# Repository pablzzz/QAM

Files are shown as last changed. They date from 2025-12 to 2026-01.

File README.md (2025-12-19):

# The Quadrant Actuator Machine (QAM)
## Introduction
The Quadrant Actuator Machine (QAM) is an arena for experimental tests that consists of a removable Petri dish, four pull-type electromagnets and four quadrant-shaped hammers, separated by a margin and two walls to minimize vibration cross-talk. A PETG 3D-printed base holds the four electromagnets fitted with hammers. Another 3D-printed structure, (the crown holding the Petri dish), sits on top of it, held in place by a pair of 3D-printed grips. See the full documentation [here](The_Quadrant_Actuator_Machine.pdf).

<p align="center">
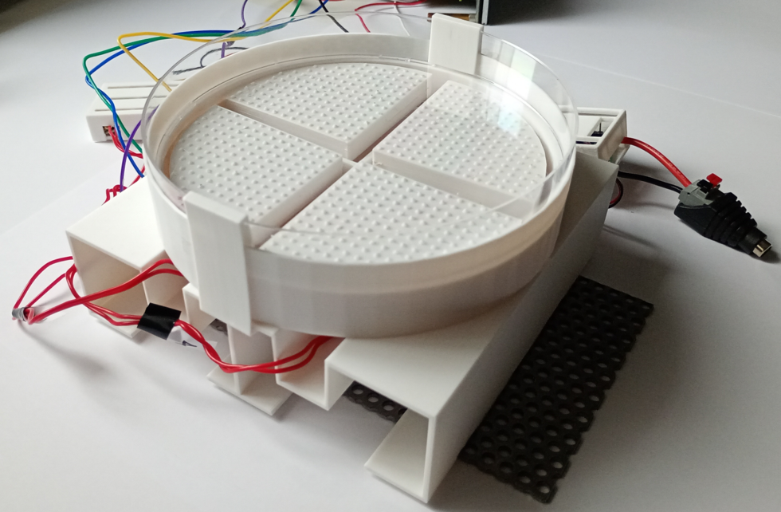
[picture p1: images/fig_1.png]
  
  Picture of the final version of the Slim QAM.
</p>

The creation of the QAM was supported by the strategic programme Excellence Initiative at Jagiellonian University, Poland (RSM/122/FP).

## Programming

The I<sup>2</sup>C PWM board was programmed in Python to drive the solenoids as shown below. The quadrants are
denoted by *Q<sub>i</sub>* where *i* is any of the 4 available quadrants in the Petri dish and *Q<sub>i</sub>* ∈ {OFF, LOW, MEDIUM, HIGH}.

| Value | Description |
|---|---|
| OFF | The electromagnet is not being acted upon. |
| LOW | The electromagnet taps the Petri dish 4 times per second. |
| MEDIUM | The electromagnet taps the Petri dish 8 times per second. |
| HIGH | The electromagnet taps the Petri dish 16 times per second. |

The Python file `quadrant_operation.py` contains all the relevant code. To operate the PCA9685, the
following library has to be installed: `adafruit-circuitpython-pca9685`. For example, to activate only the
fourth quadrant at 4 taps/s, the script can be called like this:
`pi@raspberrypi:~/qam$ quadrant_operation.py LOW [0,0,0,1]`

## Example dataset obtained using the QAM

The QAM was tested by performing experiments on a model organism to gather data to extend the Vicsek
model (a swarm behavior model).

<p align="center">
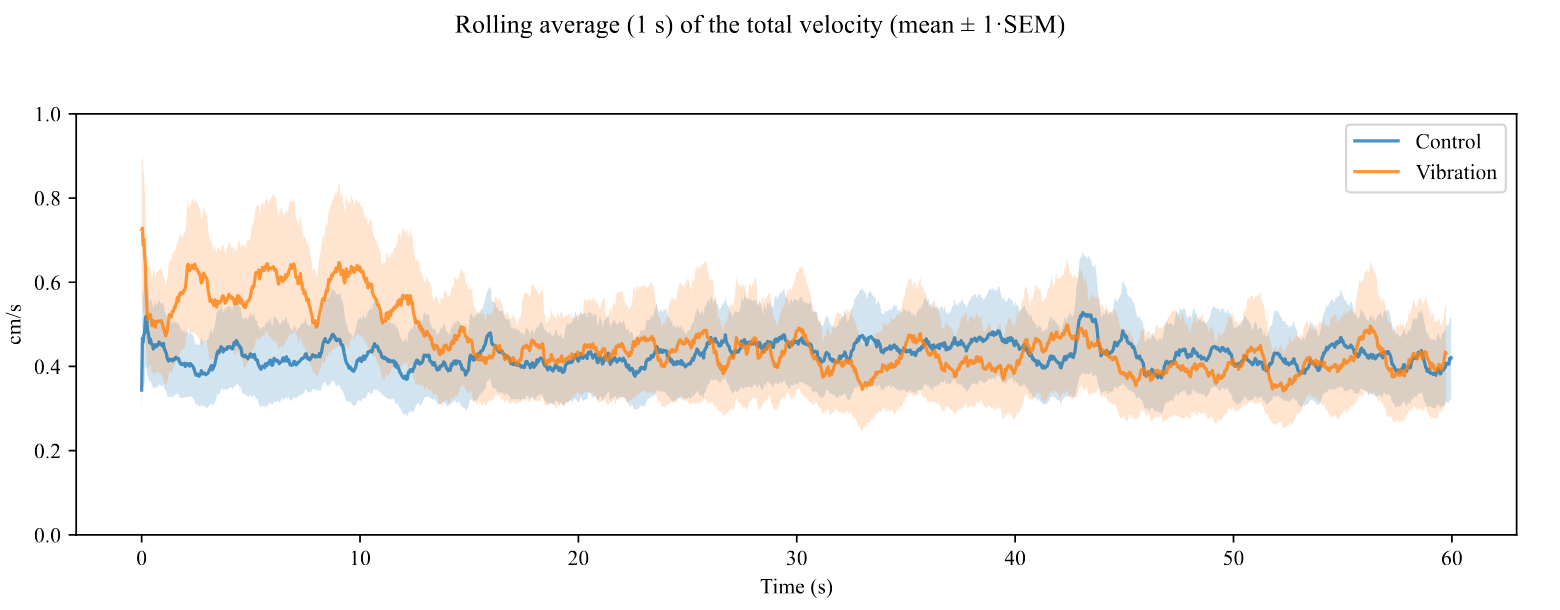
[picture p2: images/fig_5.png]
  
  Control vs Vibration setup on the QAM (speed).
</p>

<p align="center">
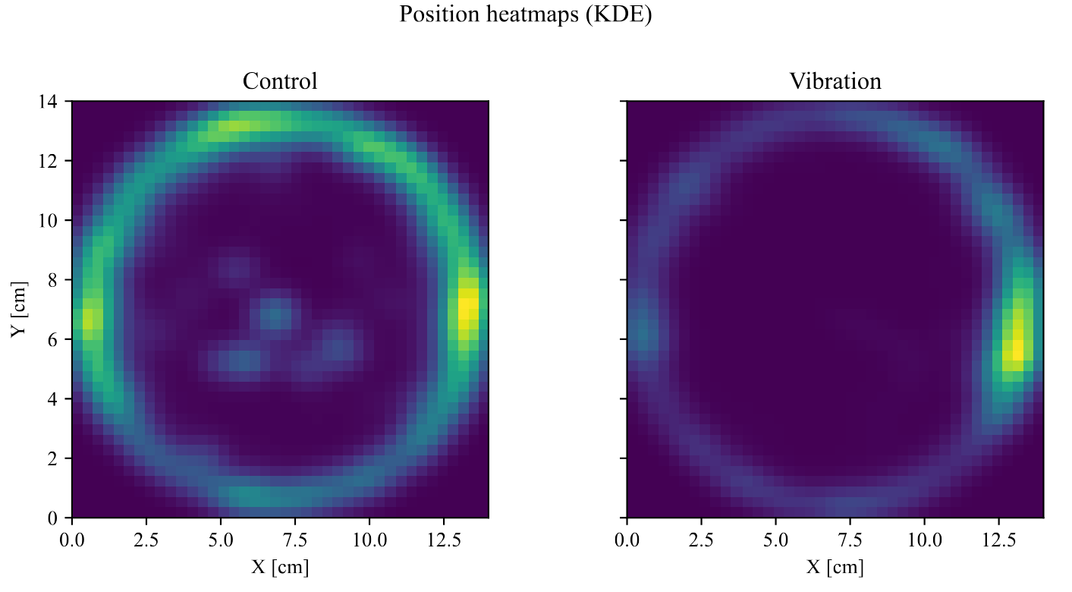
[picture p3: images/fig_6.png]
  
  Control vs Vibration setup on the QAM (KDE heatmaps). Both leftmost quadrants were active
  in the Vibration group. Note the avoidance of the active quadrants.
</p>

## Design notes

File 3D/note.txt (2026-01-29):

Prusa PETG filament was used for all 3D prints.

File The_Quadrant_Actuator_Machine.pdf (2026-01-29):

## The Quadrant Actuator Machine (QAM)

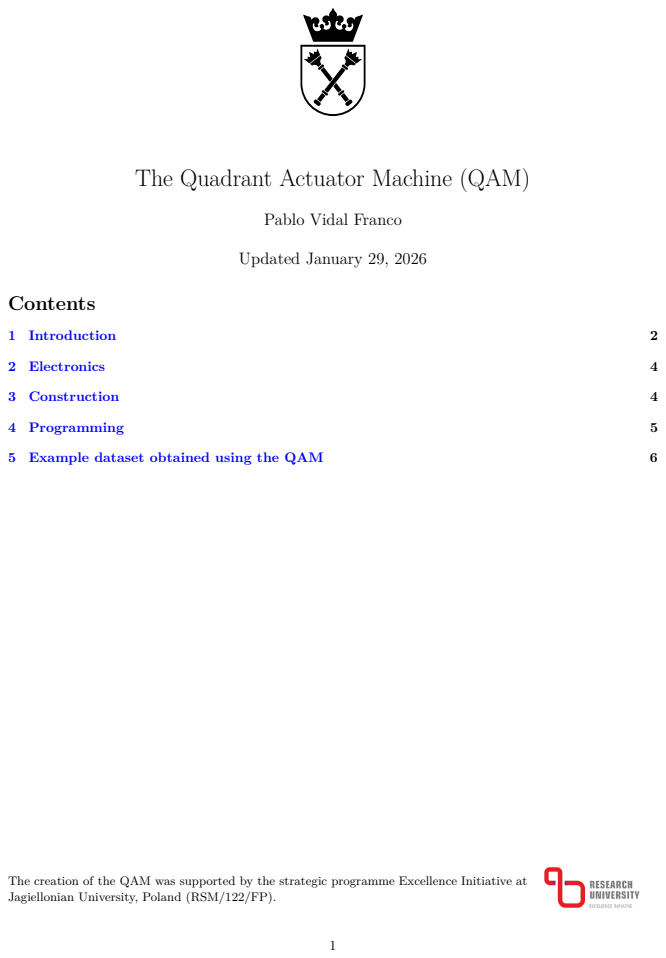
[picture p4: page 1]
Updated January 29, 2026; Contents; 1 Introduction; 2 Electronics; 3 Construction; 4 Programming; 5 Example dataset obtained using the QAM

Pablo Vidal Franco

The creation of the QAM was supported by the strategic programme Excellence Initiative at
Jagiellonian University, Poland (RSM/122/FP).

## 1 Introduction

The Quadrant Actuator Machine (QAM) is an arena for experimental tests that consists of a removable Petri dish, four pull-type electromagnets and four quadrant-shaped hammers, separated by a margin and two walls to minimize vibration cross-talk. A PETG 3D-printed base holds the four electromagnets fitted with hammers. Another 3D-printed structure, (the crown holding the Petri dish), sits on top of it, held in place by a pair of 3D-printed grips (Figure 1). A prototype of the QAM was also built but it was discarded as its weight would not make it practical for transport (Figure 2). Table 1 shows the materials used during the construction of the prototype and the final version. I designed and assembled both the final QAM and the prototype. I also tested the machine on terrestrial isopods.


Figure 1: Picture of the final version of the Slim QAM.

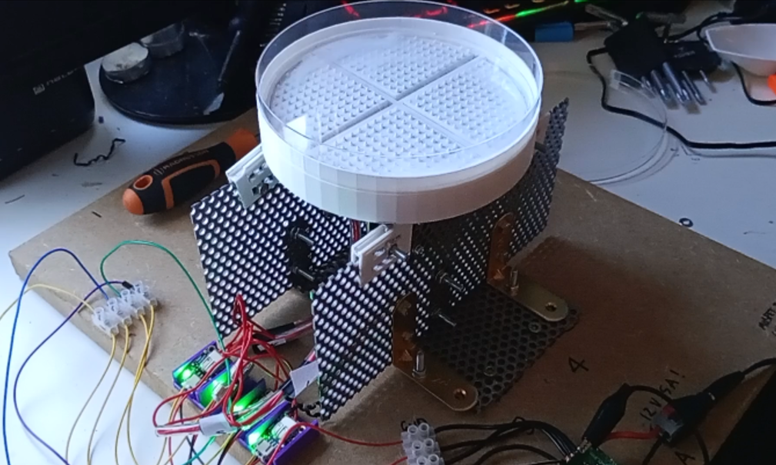
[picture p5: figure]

Figure 2: Picture of the QAM prototype.

Table 1: Materials used for the construction of the QAM prototype and the Slim QAM.

Item | Purpose | Number
140 mm diameter PET Petri dish | Removable part of machine forming the arena. | 1
40 x 30 x 2 cm wooden sheet | Main support for the steel sheets and machine. | 1
Perforated 20 x 10 x 0.2 cm steel sheet | Support for the electromagnets. | 3
M3 screw | Attach the steel sheet to the wooden sheet. | 4
L-brackets | Attach the steel sheets other steel sheets. | 6
M3 bolt, nut and washer | Attach L-brackets to the steel sheets. | 32
M1 bolt, nut and washer | Attach the 3D-printed pieces to the steel sheets. | 4
Super glue | Bolt fixing in the prototype. | 1
8 mm screw terminals 10A/250V | Wiring prototypes and final connections. | 12
PVC wire set / wire | | 1
Power supply 12V/5A | Power supply for the electromagnets. | 1
DC 5.5×2.1 mm power jack | Split the power into a PCB adapter. | 1
Adapter PCB | Distribute (+) and (-) to electromagnets. | 1
Raspberry Pi 5 | Control the electromagnets and record data. | 1
I²C PWM driver | Interface to control the electromagnets. | 1
N-channel MOSFET driver | | 4
12V 12W pull-type electromagnet | Produce vibrations on-demand (prototype). | 4
12V 8W pull-type electromagnet | Produce vibrations on-demand (final version). | 4
Solder roll | Solder connections. | 1
PETG filament roll | 3D-print prototypes and final versions of the ham-
| mers sitting on the electromagnets, and the Petri
| dish supports. | 2

## 2 Electronics

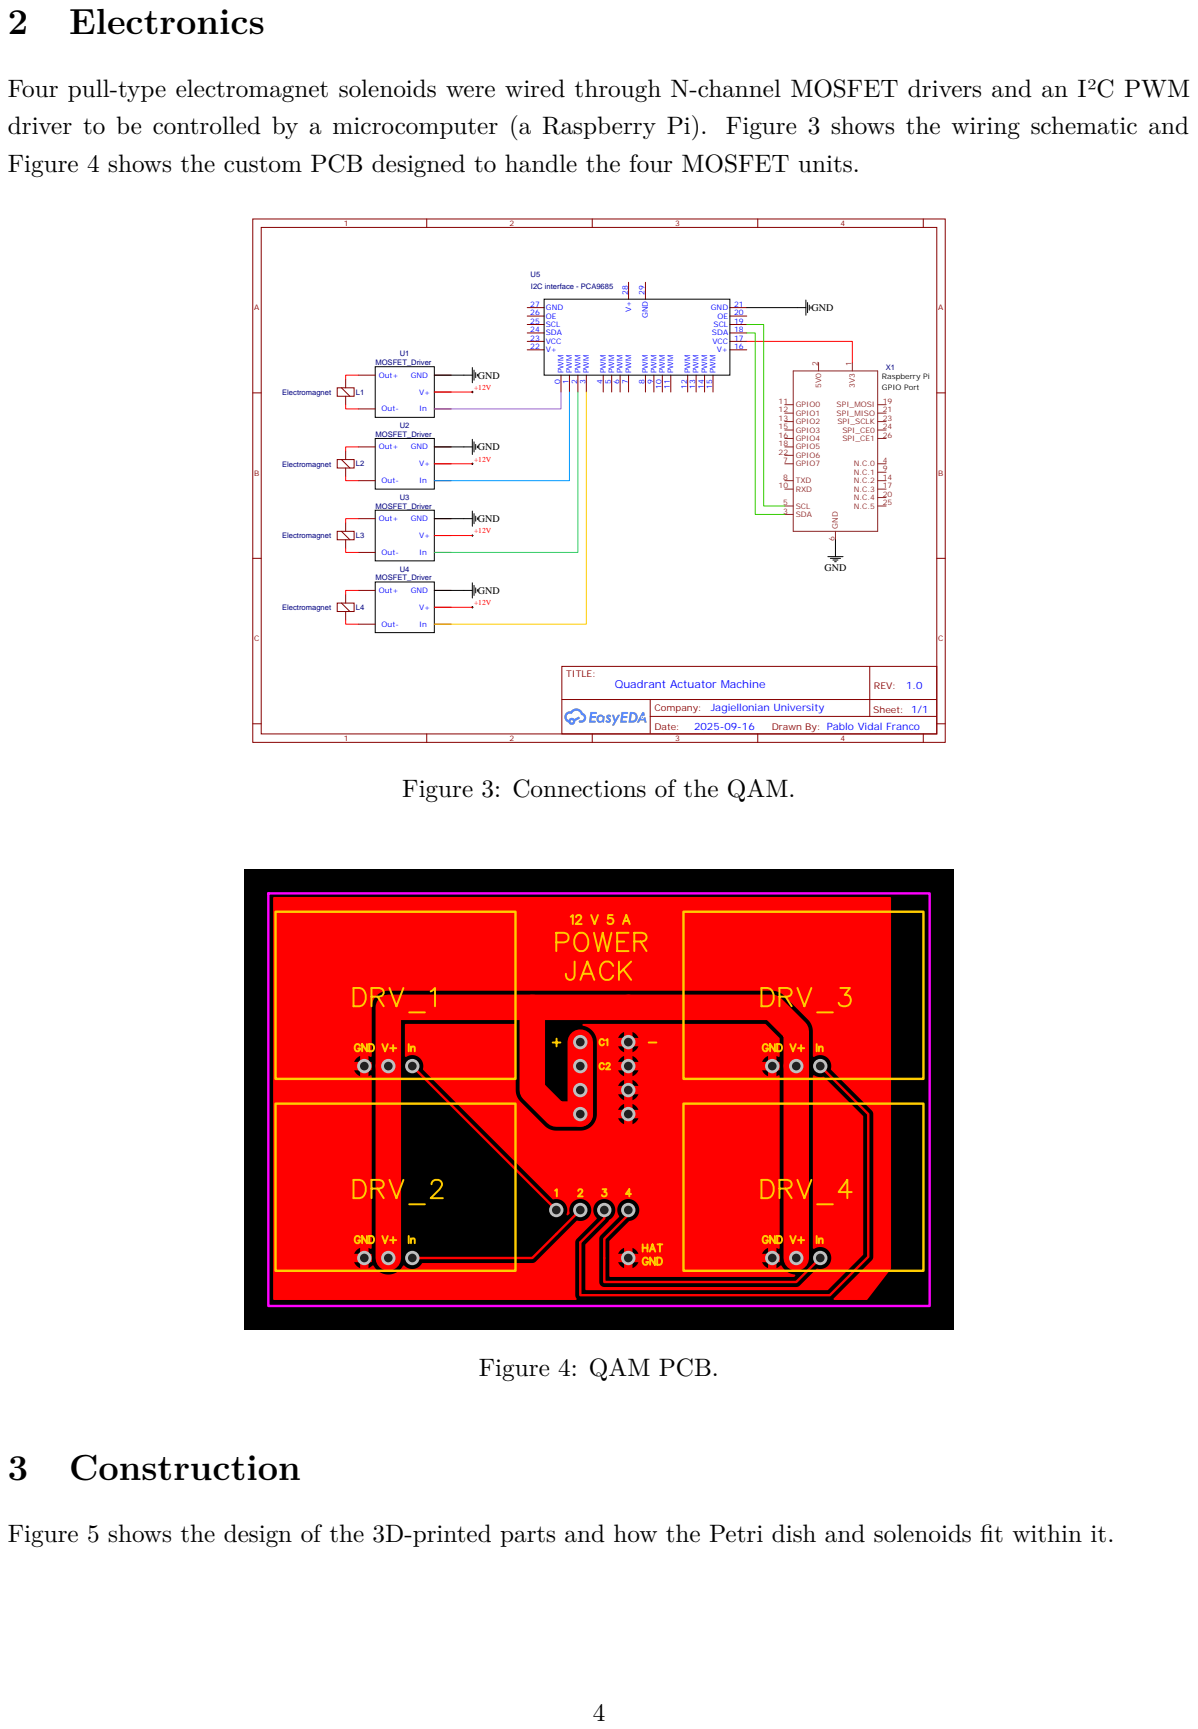
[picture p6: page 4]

Four pull-type electromagnet solenoids were wired through N-channel MOSFET drivers and an I²C PWM
driver to be controlled by a microcomputer (a Raspberry Pi). Figure 3 shows the wiring schematic and
Figure 4 shows the custom PCB designed to handle the four MOSFET units.

V+ 22 VCC 23 SDA 24 SCL 25 OE 26 GND 27

V+ 16 VCC 17 SDA 18 SCL 19 OE 20 GND 21

Drawn By: Pablo Vidal Franco

Figure 3: Connections of the QAM.

Figure 5 shows the design of the 3D-printed parts and how the Petri dish and solenoids fit within it.

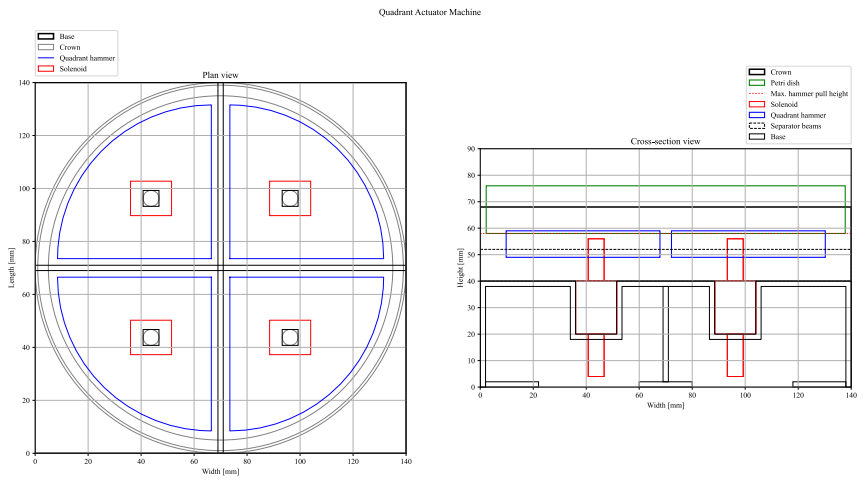
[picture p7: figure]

Figure 5: Plan view and side view of the Slim QAM.

## 4 Programming

The I²C PWM was programmed in Python to drive the solenoids as shown in Table 2. The quadrants are denoted by Qi where i is any of the 4 available quadrants in the Petri dish and Qi ∈ {OFF, LOW, MEDIUM, HIGH}.

Table 2: Values of Qi and descriptions.

Value | Description
OFF | The electromagnet is not being acted upon.
LOW | The electromagnet taps the Petri dish 4 times per second.
MEDIUM | The electromagnet taps the Petri dish 8 times per second.
HIGH | The electromagnet taps the Petri dish 16 times per second.

The Python file quadrant_operation.py contains all the relevant code. To operate the PCA9685, the following library has to be installed: adafruit-circuitpython-pca9685. For example, to activate only the fourth quadrant at 4 taps/s, the script can be called like this:

pi@raspberrypi:~/qam$ quadrant_operation.py LOW [0,0,0,1]

## 5 Example dataset obtained using the QAM

The QAM was tested by performing experiments on a model organism to gather data to extend the Vicsek

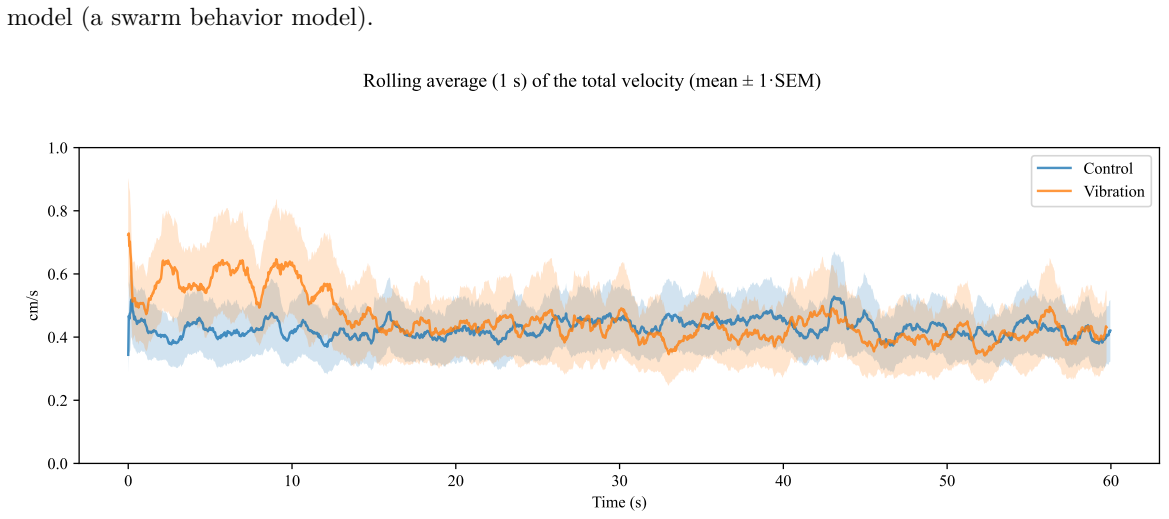
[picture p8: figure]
model (a swarm behavior model).; Time (s); Control Vibration

Rolling average (1 s) of the total velocity (mean ± 1·SEM)

Figure 6: Control vs Vibration setup on the QAM (speed).

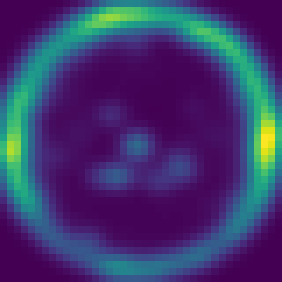
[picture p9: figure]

0.0 | 2.5 | 5.0 | 7.5 | 10.0 | 12.5
| | | X [cm]

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
### Y [cm]

## Control

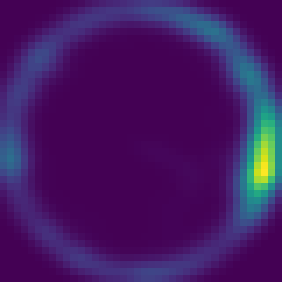
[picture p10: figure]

0.0 | 2.5 | 5.0 | 7.5 | 10.0 | 12.5
| | | X [cm]

## Vibration

## Position heatmaps (KDE)

Figure 7: Control vs Vibration setup on the QAM (KDE heatmaps). Both leftmost quadrants were active in the Vibration group. Note the avoidance of the active quadrants.

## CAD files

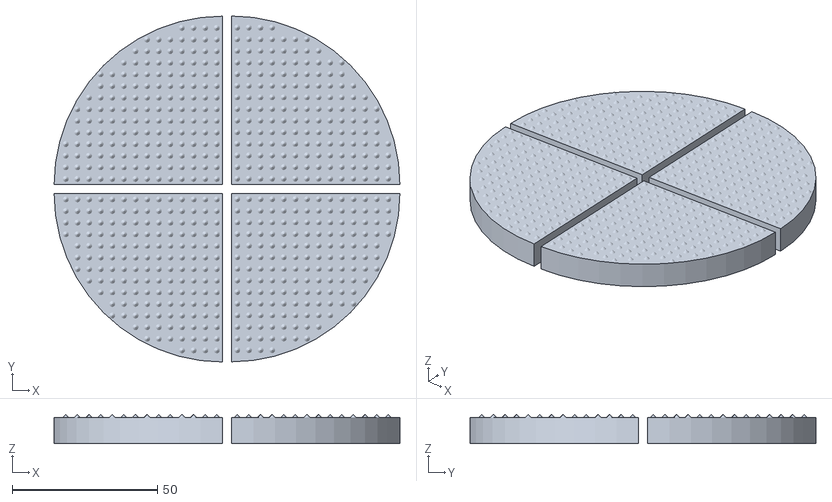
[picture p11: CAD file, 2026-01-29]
3D/vks_slim_quadrant.stl
119.1 x 119.1 x 10.0

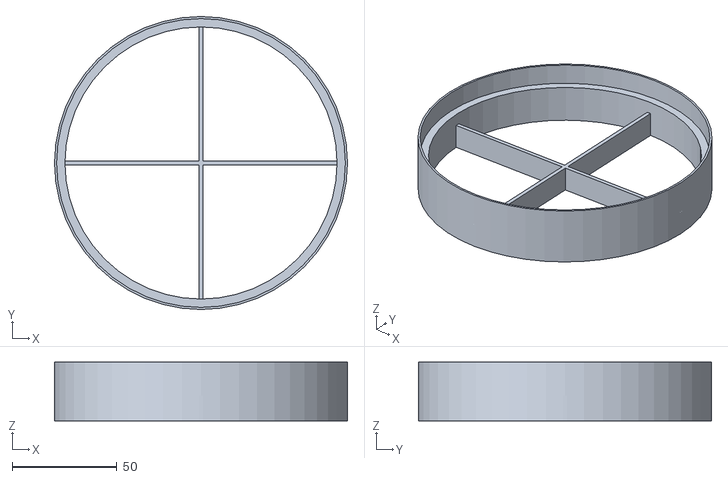
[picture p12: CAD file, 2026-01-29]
3D/vks_crown_slim.stl
140.0 x 140.0 x 28.0

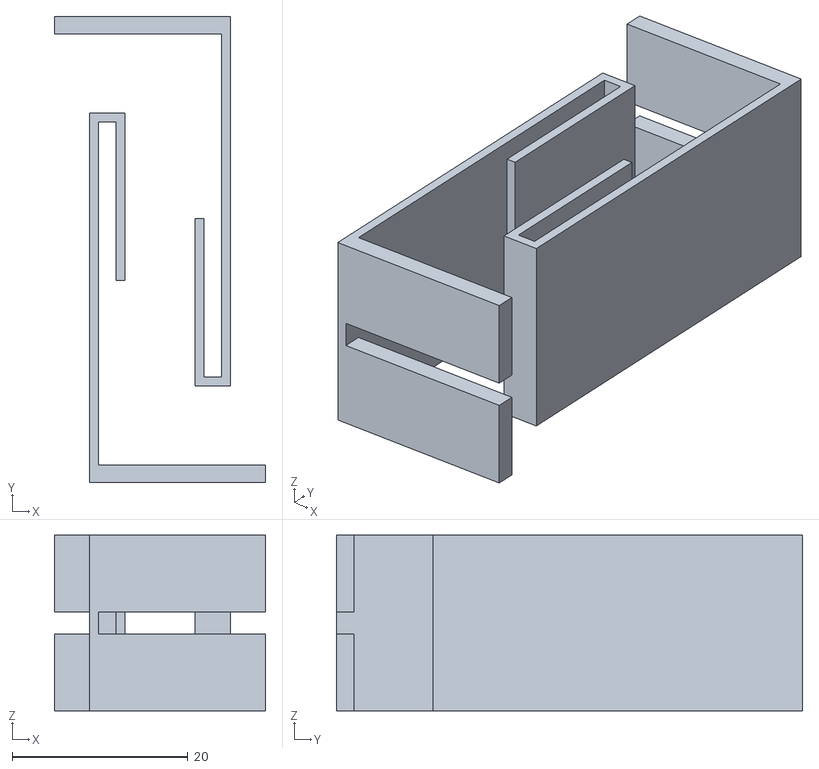
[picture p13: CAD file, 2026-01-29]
3D/vks_grip.stl
24.0 x 53.0 x 20.0

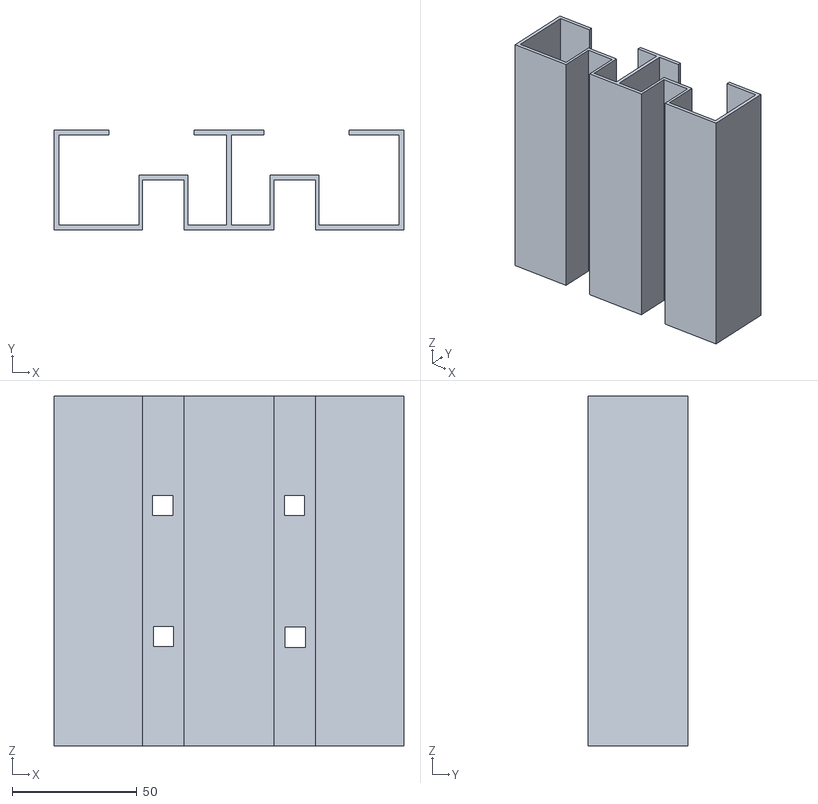
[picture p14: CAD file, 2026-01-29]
3D/vks_slim_base.stl
140.0 x 40.0 x 140.0

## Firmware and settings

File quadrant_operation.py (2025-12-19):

import sys
import ast
import time
import board
import busio
from adafruit_pca9685 import PCA9685

# Throw an error if not all args are passed
if len(sys.argv) < 3:
    raise ValueError("Pass the Q value ('LOW', 'MEDIUM', 'HIGH') and the list of active_channels, e.g. 'quadrant_operation.py LOW [0,0,0,1]'")

# Read value of Q and active_channels
Q = sys.argv[1].upper()
active_channels = ast.literal_eval(sys.argv[2])

# Throw an error if the format is not valid
if not isinstance(active_channels, list) or len(active_channels) != 4:
    raise ValueError("Please pass 4 values, e.g. '[0,0,0,1]'")

# PWM pins on the PCA9685
SOL_1 = 9
SOL_2 = 5
SOL_3 = 6
SOL_4 = 3

# Actuator channels
AVAILABLE_CHANNELS = [SOL_1, SOL_2, SOL_3, SOL_4]
CHANNELS = [ch for ch, active_channel in zip(AVAILABLE_CHANNELS, active_channels) if active_channel == 1]

print(f'Activating Qs: {CHANNELS}')

# Settings
Q_DICT = {'LOW': 4, 'MEDIUM': 8, 'HIGH': 16}
PWM_FREQ_HZ = 400
TAPS_PER_SECOND = Q_DICT[Q]
ON_MS = 120
KICK_MS = 50            
KICK_DUTY_PERCENT = 5
HOLD_DUTY_PERCENT = 30
OFF = 0

# Off-time between hits
PERIOD_MS = 1000.0 / TAPS_PER_SECOND  
REST_MS = max(0, int(PERIOD_MS) - ON_MS)

# Kick/hold time
T_KICK_MS = min(KICK_MS, ON_MS)
T_HOLD_MS = max(0, ON_MS - T_KICK_MS)

i2c = busio.I2C(board.SCL, board.SDA)
pca = PCA9685(i2c)
pca.frequency = PWM_FREQ_HZ

# Helper functions to manage kicks
def duty(percent):
    percent = max(0.0, min(100.0, float(percent)))
    return int((percent / 100.0) * 0xFFFF)

def set_channel_duty(ch, percent):
    pca.channels[ch].duty_cycle = duty(percent)

def kick_phase():
    for ch in CHANNELS:
        set_channel_duty(ch, KICK_DUTY_PERCENT)

def hold_phase():
    for ch in CHANNELS:
        set_channel_duty(ch, HOLD_DUTY_PERCENT)

def all_off():
    for ch in CHANNELS:
        set_channel_duty(ch, OFF)

# Operate the set up CHANNELS until KeyboardInterrupt
try:
    while True:
        # 1) Kick all at kick duty power
        kick_phase()
        time.sleep(T_KICK_MS / 1000.0)

        # 2) Hold all at reduced duty
        if T_HOLD_MS > 0:            
            hold_phase()
            time.sleep(T_HOLD_MS / 1000.0)

        # All channels off
        all_off()

        # Rest until next tap        
        if REST_MS > 0:
            time.sleep(REST_MS / 1000.0)

except KeyboardInterrupt:
    all_off()
    pca.deinit()
